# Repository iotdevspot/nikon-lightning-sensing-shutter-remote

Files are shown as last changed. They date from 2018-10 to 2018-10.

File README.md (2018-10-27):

# nikon-lightning-sensing-shutter-remote
This project is an implemenation of the following shutter remote: [http://fototipp.hu/light2](http://fototipp.hu/light2)

## How to deploy:

I've programmed the MCU with the .HEX file separately via pickit3, but I've added programming connector to the schematics. It's your choice how to upload the code. The board design is created by Eagle and the gerber files available too. I've created an enclosure for it but it should be refactored before I publish it because there are some issues to fix.

## How to use:

There are two phases of using this shutter remote. The first one is the setting of the sensitivity. In this mode the red and blue LEDs blink one after another. After the LEDs turn off the second phase is active. In this phase we have to adjust the sensitivity of the sensor with the potentiometer. If the blue LED lights the sensitivity is there is too much light and if the red LED lights then there is too few light. The sweet spot is where the blue LED just lights up so where we are a bit over the edge where the red changes to blue. After this we can start the remote by the pushing the button and the yellow LED lights up. This indicates the focus signal is active and the remainging green LED is for indicating the exposure. To adjoust the sensitivity on the potentiometer clockwise turn decreases and counterclockwise turn will increase the sensitivity

Peolpe in the blog's comment section claimed it works fine. I need more tests to determine wether it works well or not. My indoor tests resulted that it needs quite a bigger impulse to trigger, but probably this was the aim by the creator.

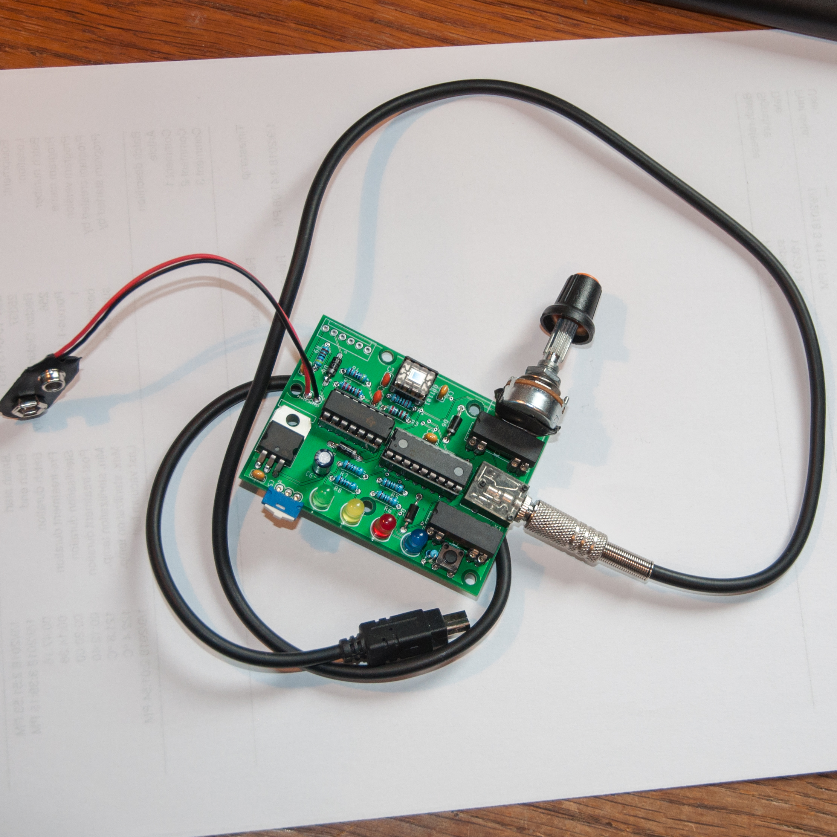
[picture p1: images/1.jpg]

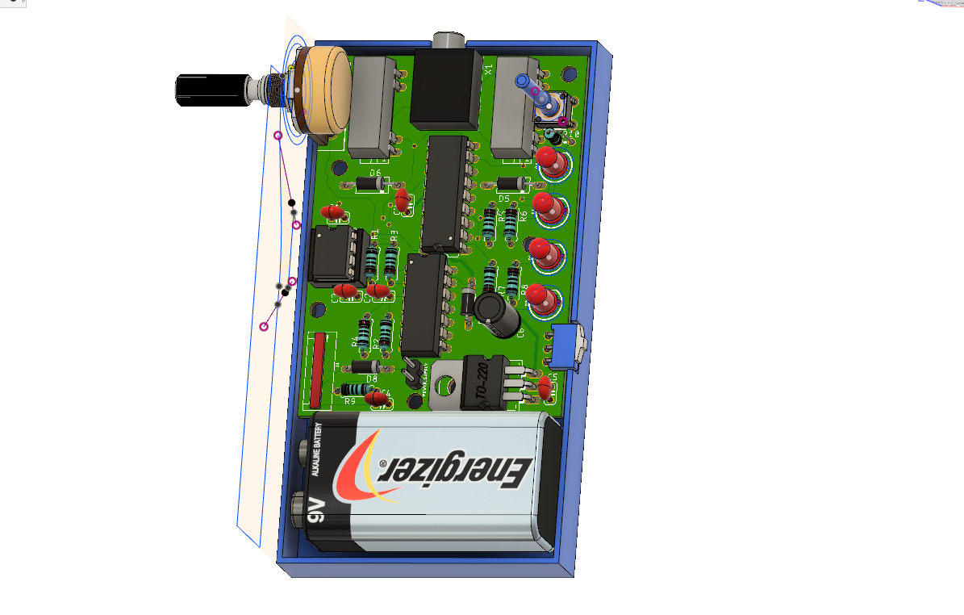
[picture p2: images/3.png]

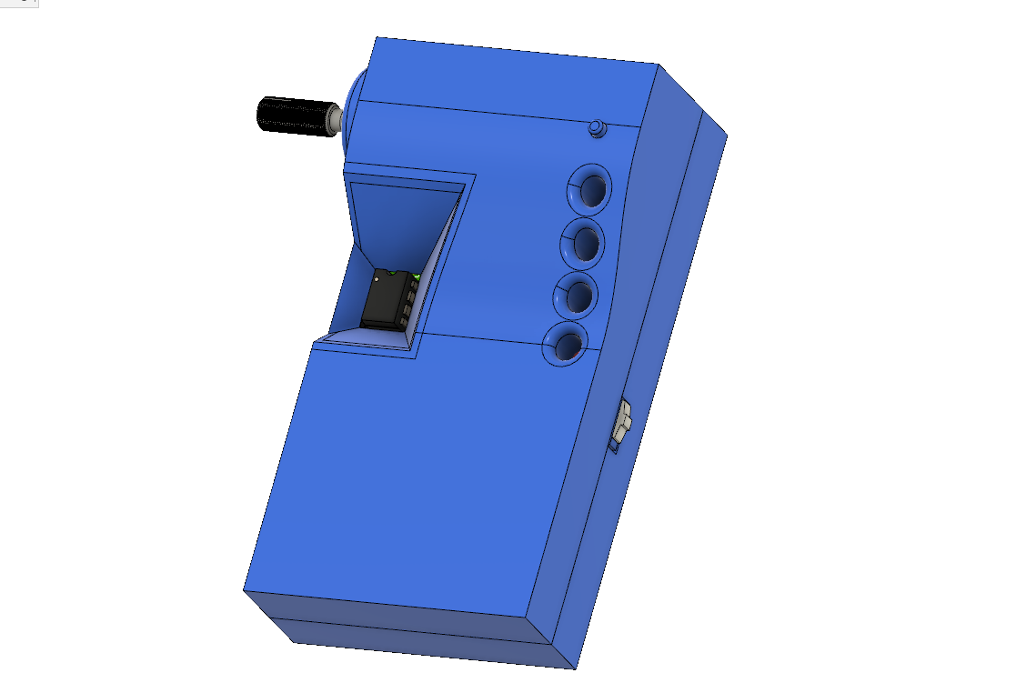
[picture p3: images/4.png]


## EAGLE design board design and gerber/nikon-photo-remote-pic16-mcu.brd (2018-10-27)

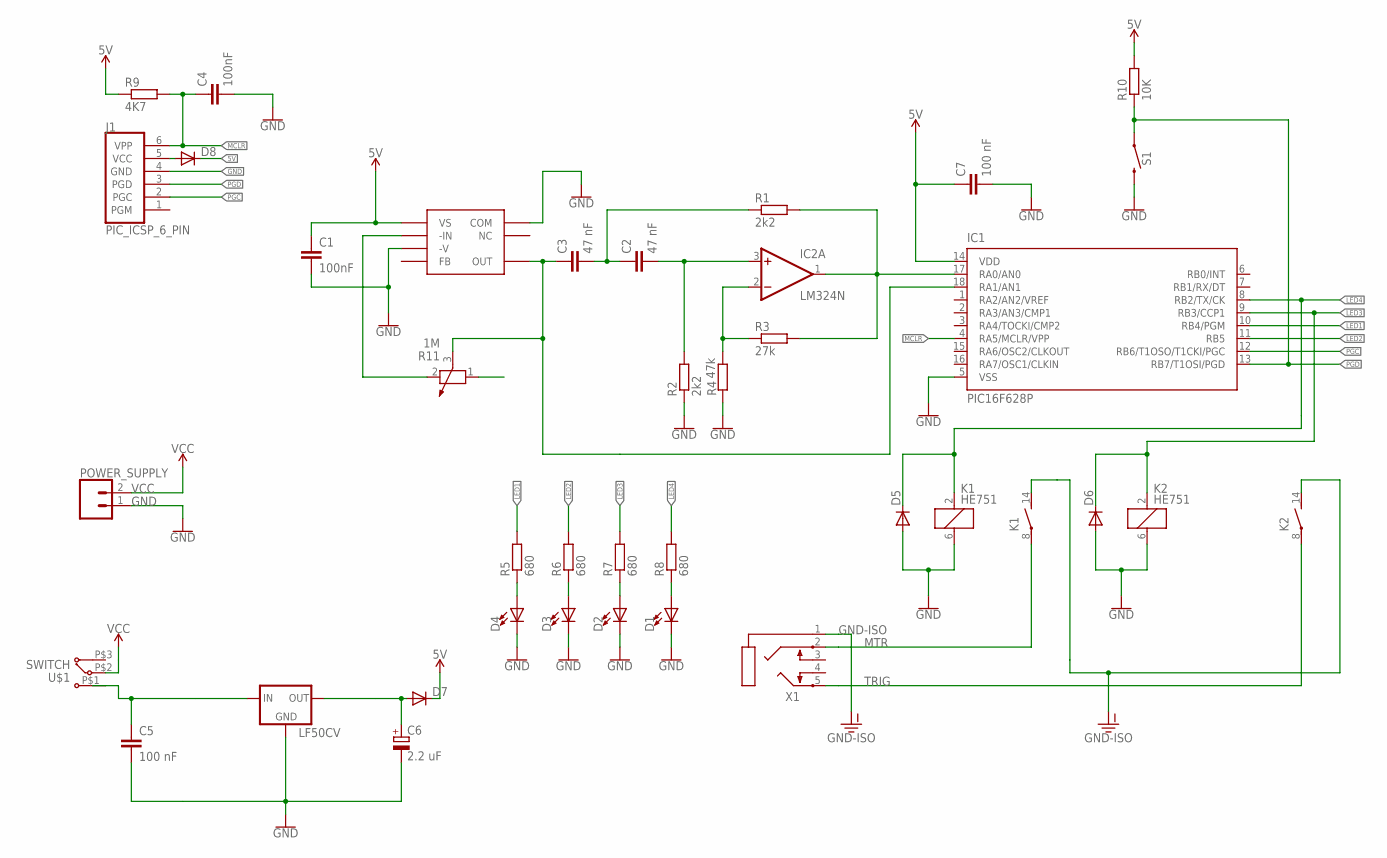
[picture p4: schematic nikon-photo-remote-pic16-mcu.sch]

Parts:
C1, C4: 100nF; C025-024X044
C2, C3: 47 nF; C025-024X044
C5, C7: 100 nF; C025-024X044
C6: 2.2 uF; E2,5-6
D1, D2, D3, D4: LED5MM; LED5MM_CLEAR
D5, D6: DIODED-10; D-10
D7, D8: DIODED-7.5; D-7.5
IC1: PIC16F628P; DIL18
IC2: LM324N; DIL14
J1: PIC_ICSP_6_PIN; MOLEX-1X6
K1, K2: HE751
LF50CV: V_REG_78XX_LAYING; 78XXL
OPT101: OPT101; DIL08
POWER_SUPPLY: CONN_02; 1X02_S
R1, R2: 2k2; 0207/7
R3: 27k; 0207/7
R4: 47k; 0207/7
R5, R6, R7, R8: 680; 0207/7
R9: 4K7; 0207/7
R10: 10K; 0204V
R11: 1M; POT_ALPHA_RV16AF-20
S1: INPUT_MOMENTARY_SWITCH_SPST-PTH-6.0MM; TACTILE_SWITCH_PTH_6.0MM
U$1: SWITCH
X1: CONN_JACK_3.5MM_PG203J; PG203J

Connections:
5V: C1.1, C7.1, D7.C, D8.C, IC1.14 (VDD), OPT101.1 (VS), R9.1, R10.2
GND: C1.2, C4.2, C5.2, C6.-, C7.2, D1.K (C), D2.K (C), D3.K (C), D4.K (C), D5.A, D6.A, IC1.5 (VSS), J1.4 (GND), K1.6 (2), K2.6 (2), LF50CV.GND, OPT101.3 (-V), OPT101.8 (COM), POWER_SUPPLY.1, R2.1, R4.2, S1.3 (2)
GND-ISO: K1.14 (S), K2.14 (S), X1.1
LED1: IC1.10 (RB4/PGM), R5.2
LED2: IC1.11 (RB5), R6.2
LED3: D6.C, IC1.9 (RB3/CCP1), K2.2 (1), R7.2
LED4: D5.C, IC1.8 (RB2/TX/CK), K1.2 (1), R8.2
MCLR: C4.1, IC1.4 (RA5/MCLR/VPP), J1.6 (VPP), R9.2
MTR: K1.8, X1.2
unnamed: C6.+, D7.A, LF50CV.OUT
unnamed: D8.A, J1.5 (VCC)
unnamed: D4.A, R5.1
unnamed: D3.A, R6.1
unnamed: D2.A, R7.1
unnamed: D1.A, R8.1
unnamed: C5.1, LF50CV.IN, U$1.P$1 (1)
unnamed: IC1.17 (RA0/AN0), IC2.1 (OUT), R1.2, R3.2
unnamed: IC2.2 (-IN), R3.1, R4.1
unnamed: C2.2, IC2.3 (+IN), R2.2
unnamed: C2.1, C3.2, R1.1
unnamed: C3.1, IC1.18 (RA1/AN1), OPT101.5 (OUT), R11.3
unnamed: OPT101.2 (-IN), R11.2
PGC: IC1.12 (RB6/T1OSO/T1CKI/PGC), J1.2 (PGC)
PGD: IC1.13 (RB7/T1OSI/PGD), J1.3 (PGD), R10.1, S1.1
TRIG: K2.8, X1.5
V+: IC2.4 (V+)
V-: IC2.11 (V-)
VCC: POWER_SUPPLY.2, U$1.P$2 (2)

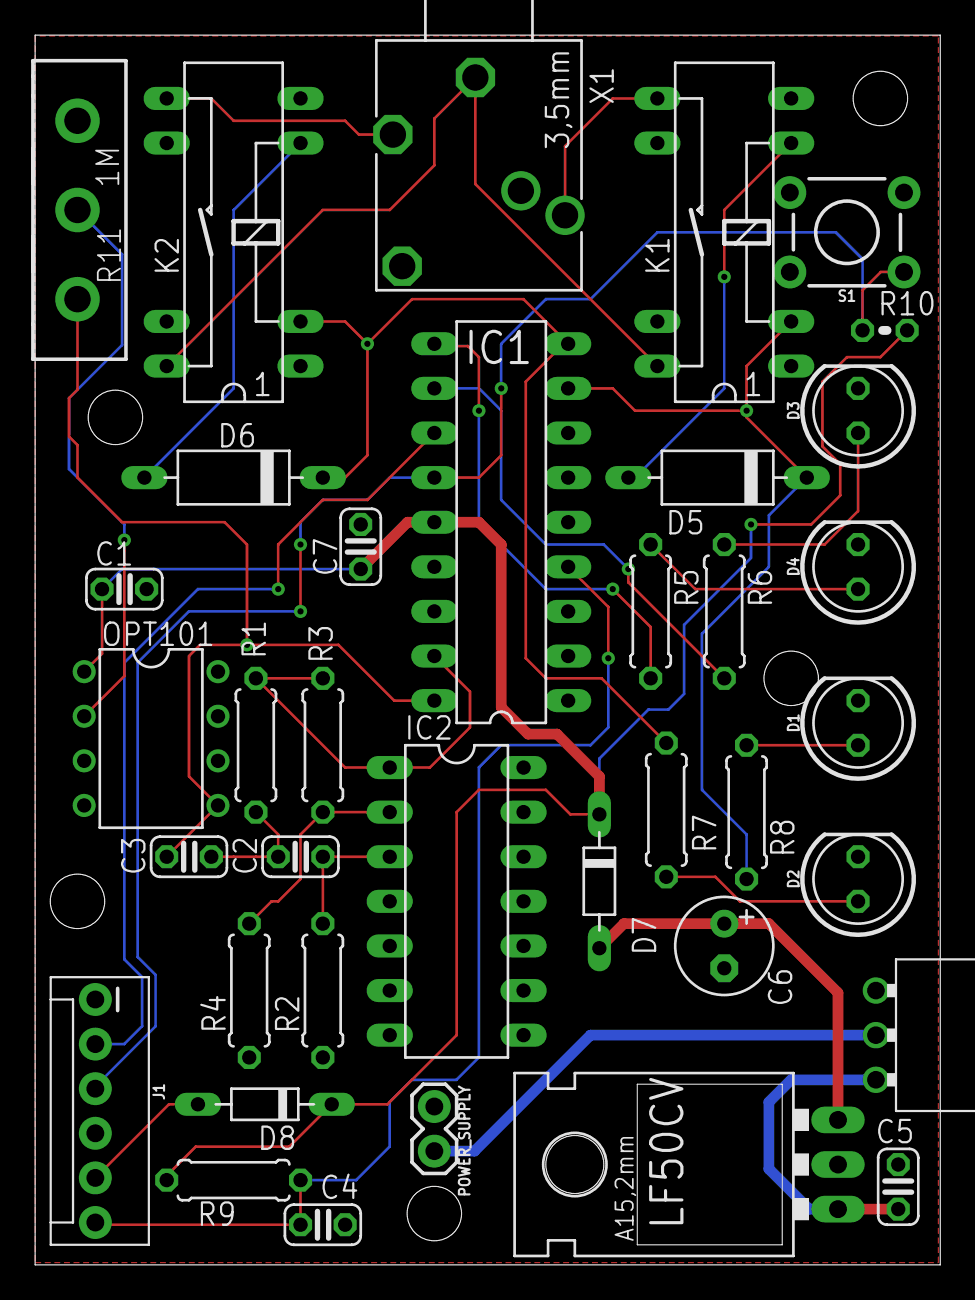
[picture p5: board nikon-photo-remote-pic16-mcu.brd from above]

Board: 2 copper layers, 51.5 x 70.0 mm, 37 parts (0 on the bottom side), 26 nets.

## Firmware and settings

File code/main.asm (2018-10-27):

	LIST	p=16F628		
	include "P16F628.inc"		
	ERRORLEVEL	0,	-302	
	__config 0x3F18			


		cblock	0x20			;start of general purpose registers
            Cz1,Cz2,Cz3
			hold			;Comparator pervious state	
  		    count			;used in looping routines
			count1			;used in delay routine
			counta			;used in delay routine
			countb			;used in delay routine
			tmp1			;temporary storage
			tmp2
			templcd			;temp store for 4 bit mode
			templcd2

			Value				; Value to be sent to LEDs
			Dirty				; Is LCD display dirty?
			Digit0				; First digit for display
			Digit1				; Second digit for display		
			Digit2				; Third digit for display
			DigitIndex			; Digit pointer
			J					; 101us delay outer loop counter
			K					; 101us delay inner loop counter
			L					; 4.1ms delay outer loop counter
			M					; 4.1ms delay inner loop counter

		endc

LCD_PORT	Equ	PORTB
LCD_TRIS	Equ	TRISB
LCD_RS		Equ	0x00			;LCD handshake lines RS PORTB RB0
LCD_RW		Equ	0x01			;RW PORTB RB1
LCD_E		Equ	0x02			;E PORTB RB2


C1OUTMASK   	Equ b'01000000'		;Comparator1 output bit
C2OUTMASK	Equ b'10000000'		;Comparator2 output bit

SW1		Equ 7				;RB7 (pin 13)
TRIGGER     	Equ 3				;RB3
METERING    	Equ 2				;RB2
LED_CAL		Equ 5				;RB5
LED_MODE	Equ 4				;RB4
		org	0x0000

;Chip funkciok inicializaslasa

      		clrf PORTA
      		clrf PORTB

		movlw 0x32       ;Internal voltage reference mode CM<2:0>=010
	 	movwf	CMCON


SetPorts	
        	bsf 	STATUS,	RP0	;select bank 1
		movlw	b'10000000'	;RB7 input RB6-0 input
		movwf	PORTB		;PORTB - Mind a 8 vezetek        
		movlw   0x07				
        	movwf   TRISA		; RA<2:0> Input RS<4:3> output

		bcf 	STATUS,	RP0	;select bank 0



;startup
calibrate1

;time to settle down
				bsf  PORTB, LED_MODE
				bcf  PORTB, LED_CAL
				call Delay250ms
				bcf  PORTB, LED_MODE
				bsf  PORTB, LED_CAL
                call Delay50ms
				bsf  PORTB, LED_MODE
				bcf  PORTB, LED_CAL
				call Delay250ms
				bcf  PORTB, LED_MODE
				bsf  PORTB, LED_CAL
                call Delay50ms
				bsf  PORTB, LED_MODE
				bcf  PORTB, LED_CAL
				call Delay250ms
				bcf  PORTB, LED_MODE
				bsf  PORTB, LED_CAL
                call Delay50ms
				bsf  PORTB, LED_MODE
				bcf  PORTB, LED_CAL
				call Delay250ms
				bcf  PORTB, LED_MODE
				bsf  PORTB, LED_CAL
                call Delay50ms
				bsf  PORTB, LED_MODE
				bcf  PORTB, LED_CAL
				call Delay250ms
				bcf  PORTB, LED_MODE
				bsf  PORTB, LED_CAL
                call Delay50ms
				bsf  PORTB, LED_MODE
				bcf  PORTB, LED_CAL
				call Delay250ms
				bcf  PORTB, LED_MODE
				bsf  PORTB, LED_CAL
                call Delay50ms
   


calibrate			call vrset1041V
				bcf  PORTB, LED_MODE		;Mode led 0
		

comploop0			bcf   PORTB, LED_CAL
				bsf   PORTB, LED_MODE
comploop1		
				btfss PORTB, SW1
				goto mode_select_switch
				
				movf CMCON,w
				andlw C2OUTMASK			;1 az output bit ?
				btfsc STATUS,Z		
		        	goto comploop0
				
				bsf PORTB,LED_CAL
                		bcf PORTB,LED_MODE
				goto comploop1


mode_select_switch
				Call Delay250ms
			
				Call vrset0625V

				bsf PORTB, LED_MODE		;mode led on
				bcf PORTB, LED_CAL		;calibrate led off
				Call Delay250ms
				bsf PORTB, LED_MODE		;mode led on
				bcf PORTB, LED_CAL		;calibrate led off
				bcf PORTB, TRIGGER
				bsf PORTB, METERING


 
Triggerloop 	btfss PORTB, SW1
				goto exit_trigger_mode

				movf CMCON,w
				andlw C1OUTMASK			;1 az output bit ?
				btfsc STATUS,Z		
		        	goto Triggerloop

       ;Trigger !!

				bsf PORTB, TRIGGER
				call Delay250ms
				call Delay250ms
				bcf  PORTB, TRIGGER
				call Delay50ms
				bcf  PORTB, METERING
				; villog
				
				bcf  PORTB, LED_MODE
				bsf  PORTB, LED_CAL
				call Delay250ms
				bsf  PORTB, LED_MODE
                		bcf  PORTB, LED_CAL
					call Delay250ms
				bcf  PORTB, LED_MODE
				bsf  PORTB, LED_CAL
				call Delay250ms
				bsf  PORTB, LED_MODE
                		bcf  PORTB, LED_CAL
				call Delay250ms
				bcf  PORTB, LED_MODE
				bsf  PORTB, LED_CAL
				call Delay250ms
				bsf  PORTB, LED_MODE
		                bcf  PORTB, LED_CAL
				call Delay250ms
				bcf  PORTB, LED_MODE
				bsf  PORTB, LED_CAL
				call Delay250ms
				bsf  PORTB, LED_MODE
                		bcf  PORTB, LED_CAL
				call Delay250ms
				bcf  PORTB, LED_MODE
				bsf  PORTB, LED_CAL
				call Delay250ms
				bsf  PORTB, LED_MODE
                		bcf  PORTB, LED_CAL
				call Delay250ms
				bcf  PORTB, LED_MODE
				bsf  PORTB, LED_CAL
				call Delay250ms
				bsf  PORTB, LED_MODE
                		bcf  PORTB, LED_CAL
				call Delay250ms
				bcf  PORTB, LED_MODE
				bsf  PORTB, LED_CAL
				call Delay250ms
				bsf  PORTB, LED_MODE
                		bcf  PORTB, LED_CAL
				call Delay250ms
				bcf  PORTB, LED_MODE
				bsf  PORTB, LED_CAL
				call Delay250ms
				bsf  PORTB, LED_MODE
                		bcf  PORTB, LED_CAL
				bsf  PORTB, METERING
				
		        	goto Triggerloop

exit_trigger_mode

				Call Delay250ms
				bcf PORTB,LED_MODE
				bcf PORTB,METERING
				goto calibrate1



;Set VREF to 1.041V
vrset1041V
		bsf 	STATUS, RP0			;select bank1
		movlw	0xE5				;1.041V (for check gain)
		movwf	VRCON
		bcf		STATUS,	RP0
        	call	Delay250ms			;Time to settle down VREF
		return
    
;Set VREF to 0.625V
vrset0625V
		bsf 	STATUS, RP0			;select bank1
		movlw	0xE3				;0.625V (for check gain)
		movwf	VRCON
		bcf		STATUS,	RP0
        	call	Delay250ms			;Time to settle down VREF
		return









Delay250ms			movlw	d'250'			;delay 250 ms (4 MHz clock)
				movwf	count1
d1A				movlw	0xC7
				movwf	counta
				movlw	0x01
				movwf	countb
Delay_0A
				decfsz	counta, f
				goto	$+2
				decfsz	countb, f
				goto	Delay_0A

				decfsz	count1	,f
				goto	d1A
				retlw	0x00


Delay50ms		movlw	d'100'			;delay 50 ms (4 MHz clock)
				movwf	count1
d1B				movlw	0xC7
				movwf	counta
				movlw	0x01
				movwf	countb
Delay_0B
				decfsz	counta, f
				goto	$+2
				decfsz	countb, f
				goto	Delay_0B

				decfsz	count1	,f
				goto	d1B
				retlw	0x00




		end

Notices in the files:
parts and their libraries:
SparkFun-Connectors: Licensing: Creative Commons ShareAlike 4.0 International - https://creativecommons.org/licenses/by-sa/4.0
